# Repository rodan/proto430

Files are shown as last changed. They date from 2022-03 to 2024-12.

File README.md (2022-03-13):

## proto430

 ////// UNDER DEVELOPMENT ///////////////////////

 BoosterPack-compatible development boards used for quick prototyping and interfacing with i2c/spi/uart-based devices

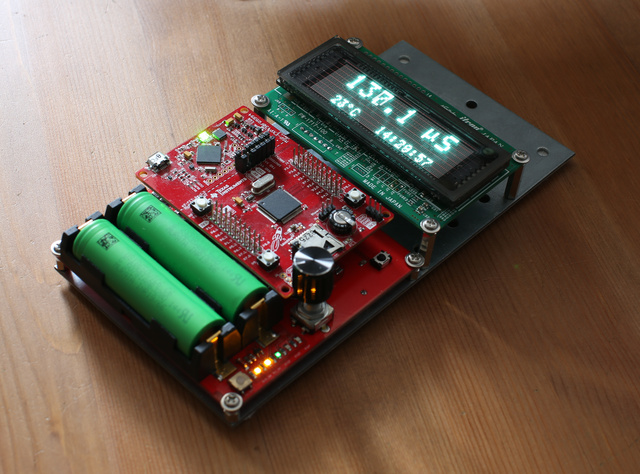
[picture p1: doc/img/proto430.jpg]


```
 source:       https://github.com/rodan/proto430
 author:       Petre Rodan <2b4eda@subdimension.ro>
 license:      BSD
```

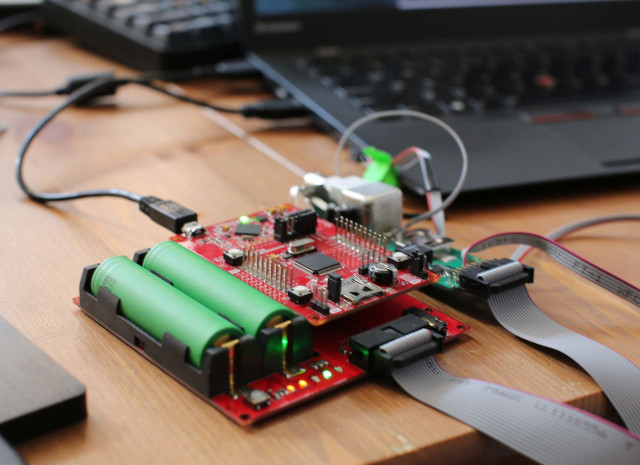
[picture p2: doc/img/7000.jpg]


### Components

Collection of plug-in Booster-Pack PCBs compatible with the Texas Instruments LaunchPad development ecosystem. one board provides access to any 3v3 device via a serial interface, the other brings access to a graphical VFD display, a rotary encoder and also has infrared remote input. the two will be linked via i2c or spi.

project directory structure

 * ./hardware/display.* - eagle-based schematics and pcbs for the spi-based Noritake VFD 
 * ./hardware/sensor.*  - eagle-based schematics and pcbs for the i2c/spi/uart devboard
 * ./hardware/vfd.* - firmware for the display pcb

testing is done with MSP-EXP430FR5994 development kits

### Build requirements

you will need TI's excelent [GCC toolchain](https://www.ti.com/tool/MSP430-GCC-OPENSOURCE) or Code Composer Studio for linux and my [reference libraries for msp430 micros](https://github.com/rodan/atlas430) cloned in /opt/.

```
cd ./firmware
make
make install
```

the devboard has been modified by adding a 16MHz high frequency crystal and two load capacitors. if these components are missing from your board then make sure to disable the *USE_XT2* define from the Makefile or CCS.

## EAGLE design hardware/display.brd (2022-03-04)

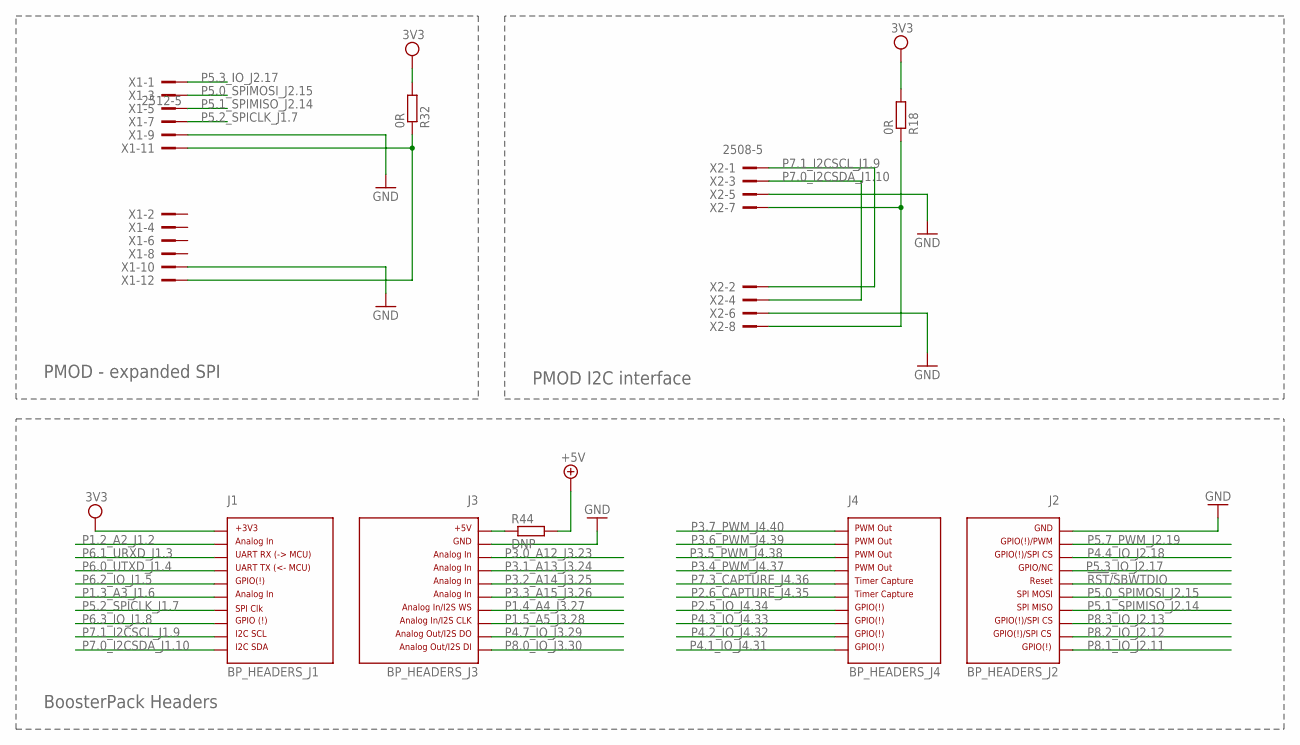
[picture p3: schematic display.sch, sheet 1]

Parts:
J1: BP_HEADERS_J1; J1
J2: BP_HEADERS_J2; J2
J3: BP_HEADERS_J3; J3
J4: BP_HEADERS_J4; J4
R18, R32: 0R; 0204V
R44: DNP; R0805W
X1: 2512-5; PAK100/2500-5-12
X2: 2508-5; PAK100/2500-5-08

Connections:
3V3: J1.1, R18.2, R32.2; also elsewhere on the board
!RST!/SBWTDIO: J2.16
+5V: R44.2; also elsewhere on the board
GND: J2.20, J3.22, X1.9, X1.10, X2.5, X2.6; also elsewhere on the board
unnamed: R18.1, X2.7, X2.8
unnamed: R32.1, X1.11, X1.12
unnamed: J3.21, R44.1
P1.2_A2_J1.2: J1.2; also elsewhere on the board
P1.3_A3_J1.6: J1.6; also elsewhere on the board
P1.4_A4_J3.27: J3.27; also elsewhere on the board
P1.5_A5_J3.28: J3.28; also elsewhere on the board
P2.5_IO_J4.34: J4.34; also elsewhere on the board
P2.6_CAPTURE_J4.35: J4.35; also elsewhere on the board
P3.0_A12_J3.23: J3.23; also elsewhere on the board
P3.1_A13_J3.24: J3.24; also elsewhere on the board
P3.2_A14_J3.25: J3.25; also elsewhere on the board
P3.3_A15_J3.26: J3.26; also elsewhere on the board
P3.4_PWM_J4.37: J4.37
P3.5_PWM_J4.38: J4.38
P3.6_PWM_J4.39: J4.39
P3.7_PWM_J4.40: J4.40
P4.1_IO_J4.31: J4.31
P4.2_IO_J4.32: J4.32
P4.3_IO_J4.33: J4.33
P4.4_IO_J2.18: J2.18; also elsewhere on the board
P4.7_IO_J3.29: J3.29
P5.0_SPIMOSI_J2.15: J2.15, X1.3; also elsewhere on the board
P5.1_SPIMISO_J2.14: J2.14, X1.5; also elsewhere on the board
P5.2_SPICLK_J1.7: J1.7, X1.7; also elsewhere on the board
P5.3_IO_J2.17: J2.17, X1.1
P5.7_PWM_J2.19: J2.19; also elsewhere on the board
P6.0_UTXD_J1.4: J1.4
P6.1_URXD_J1.3: J1.3
P6.2_IO_J1.5: J1.5
P6.3_IO_J1.8: J1.8; also elsewhere on the board
P7.0_I2CSDA_J1.10: J1.10, X2.3, X2.4; also elsewhere on the board
P7.1_I2CSCL_J1.9: J1.9, X2.1, X2.2; also elsewhere on the board
P7.3_CAPTURE_J4.36: J4.36; also elsewhere on the board
P8.0_IO_J3.30: J3.30
P8.1_IO_J2.11: J2.11; also elsewhere on the board
P8.2_IO_J2.12: J2.12; also elsewhere on the board
P8.3_IO_J2.13: J2.13; also elsewhere on the board

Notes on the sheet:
BoosterPack Headers
PMOD - expanded SPI
PMOD I2C interface

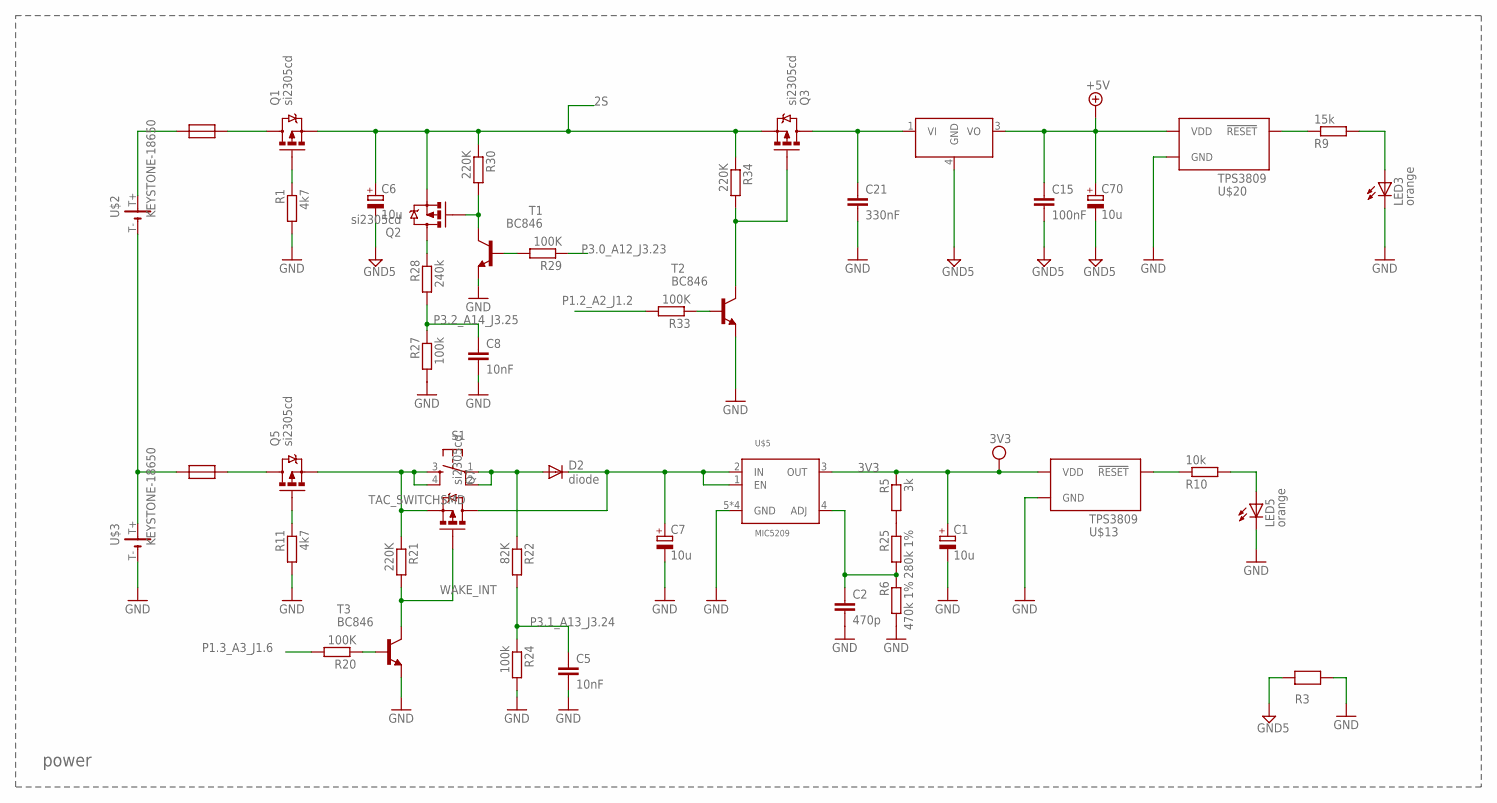
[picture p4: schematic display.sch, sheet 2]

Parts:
C1, C6, C7, C70: 10u; 153CLV-0405
C2: 470p; C0805
C5, C8: 10nF; C0805
C15: 100nF; C0805
C21: 330nF; C0805
D2: diode; SMA-DIODE
LED3, LED5: orange; CHIPLED_0805
Q1, Q2, Q3, Q5, Q7: si2305cd; SOT23-3_POWER
R1, R11: 4k7; R0805W
R3: 0R_0805; R0805W
R5: 3k; R0805W
R6: 470k 1%; R0805W
R9: 15k; R0805W
R10: 10k; R0805W
R20, R29, R33: 100K; R0805W
R21, R30, R34: 220K; R0805W
R22: 82K; R0805W
R24, R27: 100k; R0805W
R25: 280k 1%; R0805W
R28: 240k; R0805W
S1: TAC_SWITCHSMD; TACTILE-SWITCH-SMD
T1, T2, T3: BC846; SOT23
U4: 7805; D2PACK
U$2, U$3: KEYSTONE-18650; KEYSTONE_COMBO_18650
U$5: MIC5209; SO-08
U$7, U$8: Fuse 1A; 0805W
U$13, U$20: TPS3809; R_PDSO_G3

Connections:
2S: C6.+, Q1.2 (S), Q2.2 (S), Q3.2 (S), R30.1, R34.1; also elsewhere on the board
3V3: C1.+, R5.1, U$5.3 (OUT), U$13.P$3 (VDD); also elsewhere on the board
+5V: C15.1, C70.+, U4.3 (VO), U$20.P$3 (VDD); also elsewhere on the board
GND: C1.-, C2.2, C5.2, C7.-, C8.2, C21.2, LED3.C, LED5.C, R1.2, R3.2, R6.2, R11.2, R24.2, R27.2, T1.2 (E), T2.2 (E), T3.2 (E), U$3.T- (-), U$5.5 (GND), U$5.6 (GND), U$5.7 (GND), U$5.8 (GND), U$13.P$1 (GND), U$20.P$1 (GND); also elsewhere on the board
GND5: C6.-, C15.2, C70.-, R3.1, U4.4 (GND); also elsewhere on the board
unnamed: C21.1, Q3.3 (D), U4.1 (VI)
unnamed: Q1.1 (G), R1.1
unnamed: Q5.2 (S), Q7.2 (S), R21.1, S1.3, S1.4
unnamed: LED3.A, R9.2
unnamed: C2.1, R6.1, R25.2, U$5.4 (ADJ)
unnamed: Q1.3 (D), U$7.2
unnamed: Q5.3 (D), U$8.2
unnamed: R9.1, U$20.P$2 (!RESET)
unnamed: LED5.A, R10.2
unnamed: R10.1, U$13.P$2 (!RESET)
unnamed: C7.+, D2.C, Q7.3 (D), U$5.1 (EN), U$5.2 (IN)
unnamed: Q5.1 (G), R11.1
unnamed: R5.2, R25.1
unnamed: Q2.3 (D), R28.1
unnamed: Q2.1 (G), R30.2, T1.3 (C)
unnamed: R20.1, T3.1 (B)
unnamed: R29.2, T1.1 (B)
unnamed: R33.1, T2.1 (B)
unnamed: Q3.1 (G), R34.2, T2.3 (C)
N_BAT1: U$2.T- (-), U$3.T+ (+), U$8.1
N_BAT2: U$2.T+ (+), U$7.1
P1.2_A2_J1.2: R33.2; also elsewhere on the board
P1.3_A3_J1.6: R20.2; also elsewhere on the board
P3.0_A12_J3.23: R29.1; also elsewhere on the board
P3.1_A13_J3.24: C5.1, R22.2, R24.1; also elsewhere on the board
P3.2_A14_J3.25: C8.1, R27.1, R28.2; also elsewhere on the board
PUSH: D2.A, R22.1, S1.1, S1.2
WAKE_INT: Q7.1 (G), R21.2, T3.3 (C); also elsewhere on the board

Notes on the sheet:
power

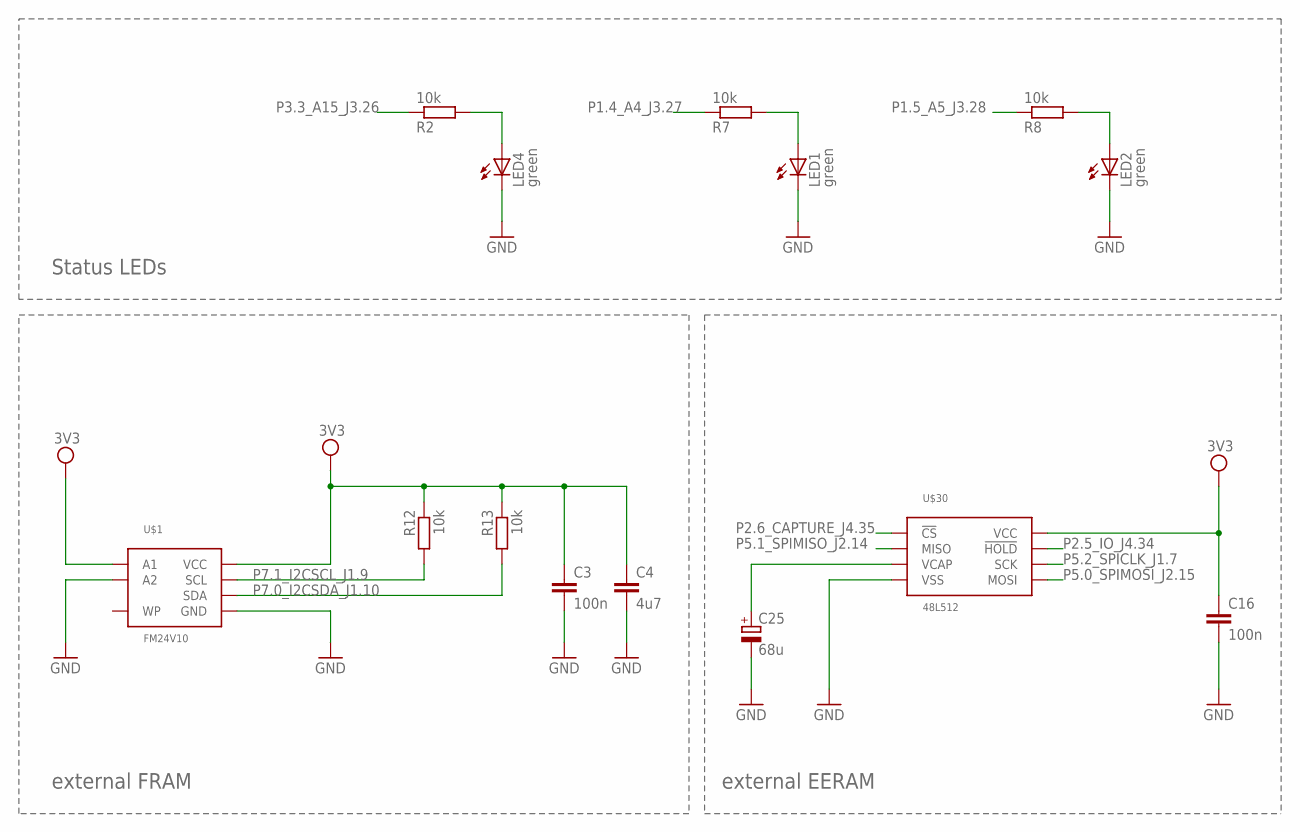
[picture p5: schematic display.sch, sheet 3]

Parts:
C3, C16: 100n; C0805
C4: 4u7; C0805
C25: 68u; SANYO-OSCON_SMD_C6
LED1, LED2, LED4: green; CHIPLED_0805
R2, R7, R8, R12, R13: 10k; R0805W
U$1: FM24V10; SO-08
U$30: 48L512; SO-08

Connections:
3V3: C3.1, C4.1, C16.1, R12.1, R13.1, U$1.2 (A1), U$1.8 (VCC), U$30.8 (VCC); also elsewhere on the board
GND: C3.2, C4.2, C16.2, C25.-, LED1.C, LED2.C, LED4.C, U$1.3 (A2), U$1.4 (GND), U$30.4 (VSS); also elsewhere on the board
unnamed: LED4.A, R2.2
unnamed: LED1.A, R7.2
unnamed: LED2.A, R8.2
unnamed: C25.+, U$30.3 (VCAP)
P1.4_A4_J3.27: R7.1; also elsewhere on the board
P1.5_A5_J3.28: R8.1; also elsewhere on the board
P2.5_IO_J4.34: U$30.7 (!HOLD); also elsewhere on the board
P2.6_CAPTURE_J4.35: U$30.1 (!CS); also elsewhere on the board
P3.3_A15_J3.26: R2.1; also elsewhere on the board
P5.0_SPIMOSI_J2.15: U$30.5 (MOSI); also elsewhere on the board
P5.1_SPIMISO_J2.14: U$30.2 (MISO); also elsewhere on the board
P5.2_SPICLK_J1.7: U$30.6 (SCK); also elsewhere on the board
P7.0_I2CSDA_J1.10: R13.2, U$1.5 (SDA); also elsewhere on the board
P7.1_I2CSCL_J1.9: R12.2, U$1.6 (SCL); also elsewhere on the board

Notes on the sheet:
external FRAM
Status LEDs
external EERAM

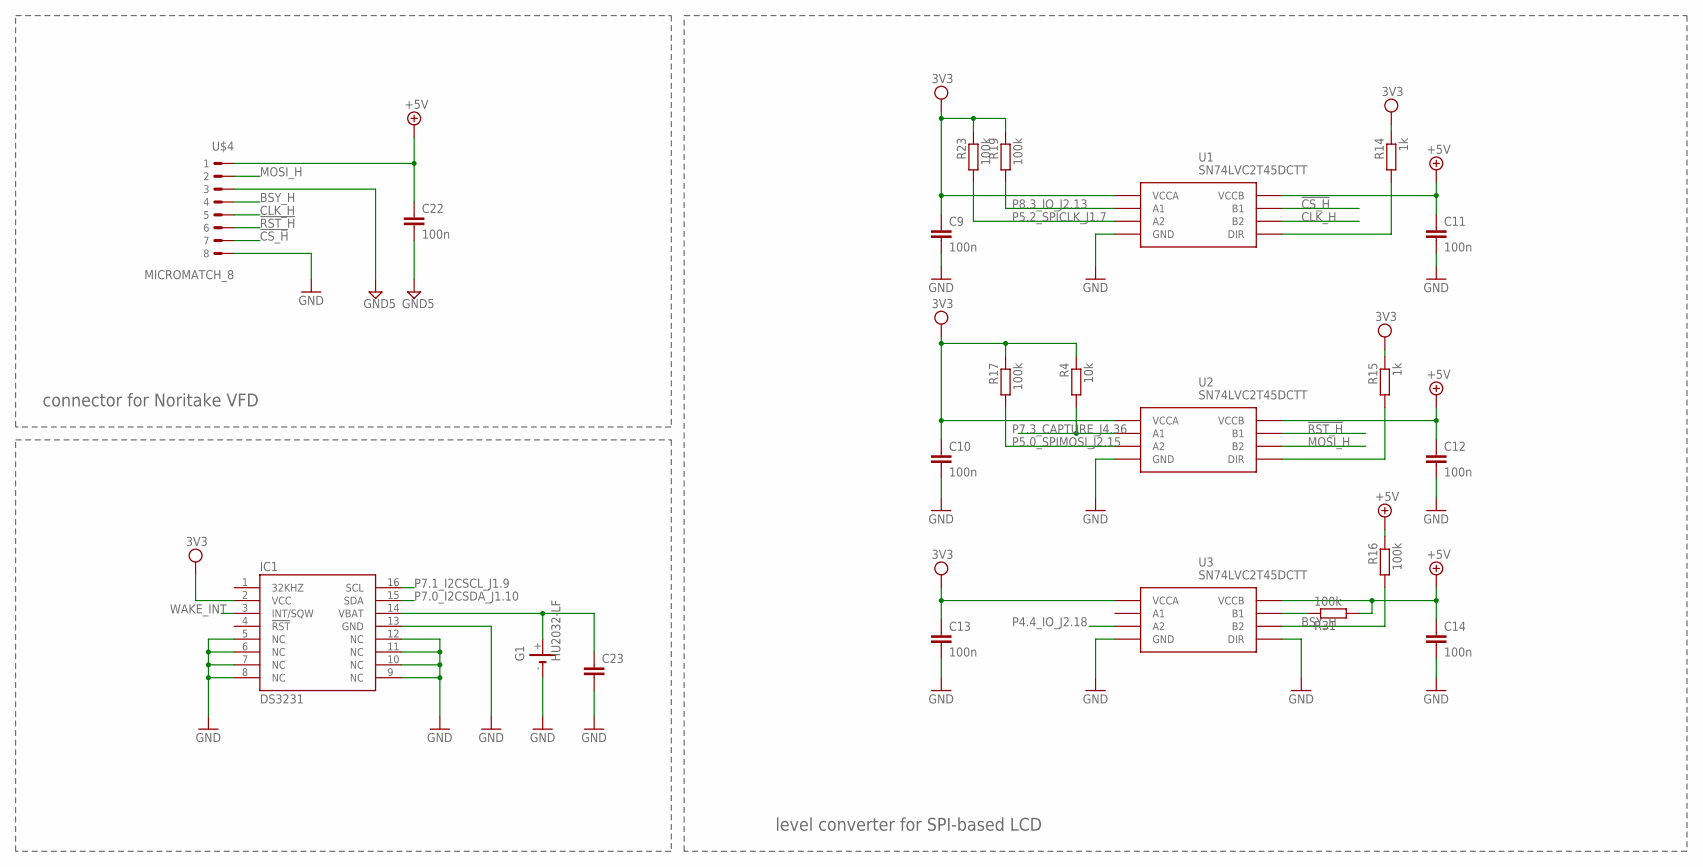
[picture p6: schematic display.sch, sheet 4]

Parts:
C9, C10, C11, C12, C13, C14, C22: 100n; C0805
C23: C-EU102-054X133; C102-054X133
G1: HU2032-LF
IC1: DS3231; SO-16
R4: 10k; R0805W
R14, R15: 1k; R0805W
R16, R17, R19, R23, R31: 100k; R0805W
U1, U2, U3: SN74LVC2T45DCTT; SSOP8
U$4: MICROMATCH_8; MICROMATCH8

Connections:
3V3: C9.1, C10.1, C13.1, IC1.2 (VCC), R4.1, R14.1, R15.1, R17.1, R19.1, R23.1, U1.P$1 (VCCA), U2.P$1 (VCCA), U3.P$1 (VCCA); also elsewhere on the board
!CS_H: U1.P$7 (B1), U$4.P$7 (7)
!RST_H: U2.P$7 (B1), U$4.P$6 (6)
+5V: C11.1, C12.1, C14.1, C22.1, R16.1, R31.2, U1.P$8 (VCCB), U2.P$8 (VCCB), U3.P$8 (VCCB), U$4.P$1 (1); also elsewhere on the board
BSY_H: R16.2, U3.P$6 (B2), U$4.P$4 (4)
CLK_H: U1.P$6 (B2), U$4.P$5 (5)
GND: C9.2, C10.2, C11.2, C12.2, C13.2, C14.2, C23.2, G1.-, IC1.5 (NC), IC1.6 (NC), IC1.7 (NC), IC1.8 (NC), IC1.9 (NC), IC1.10 (NC), IC1.11 (NC), IC1.12 (NC), IC1.13 (GND), U1.P$4 (GND), U2.P$4 (GND), U3.P$4 (GND), U3.P$5 (DIR), U$4.P$8 (8); also elsewhere on the board
GND5: C22.2, U$4.P$3 (3); also elsewhere on the board
MOSI_H: U2.P$6 (B2), U$4.P$2 (2)
unnamed: R14.2, U1.P$5 (DIR)
unnamed: R15.2, U2.P$5 (DIR)
unnamed: R31.1, U3.P$7 (B1)
unnamed: C23.1, G1.+, IC1.14 (VBAT)
P4.4_IO_J2.18: U3.P$3 (A2); also elsewhere on the board
P5.0_SPIMOSI_J2.15: R17.2, U2.P$3 (A2); also elsewhere on the board
P5.2_SPICLK_J1.7: R23.2, U1.P$3 (A2); also elsewhere on the board
P7.0_I2CSDA_J1.10: IC1.15 (SDA); also elsewhere on the board
P7.1_I2CSCL_J1.9: IC1.16 (SCL); also elsewhere on the board
P7.3_CAPTURE_J4.36: R4.2, U2.P$2 (A1); also elsewhere on the board
P8.3_IO_J2.13: R19.2, U1.P$2 (A1); also elsewhere on the board
WAKE_INT: IC1.3 (INT/SQW); also elsewhere on the board

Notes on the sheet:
connector for Noritake VFD
level converter for SPI-based LCD

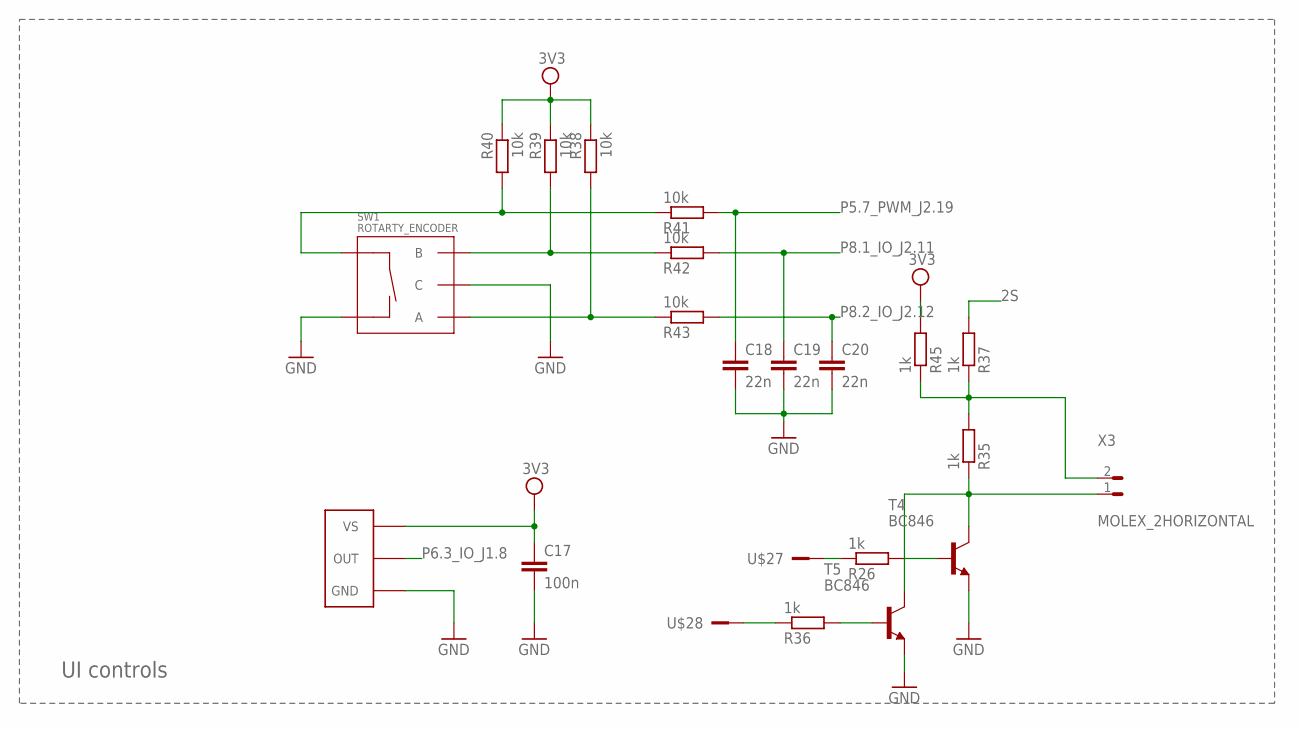
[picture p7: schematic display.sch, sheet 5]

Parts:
C17: 100n; C0805
C18, C19, C20: 22n; C0805
R26, R35, R36, R37, R45: 1k; R0805W
R38, R39, R40, R41, R42, R43: 10k; R0805W
SW1: ROTARTY_ENCODER; ROTARY_ENC_PLAIN
T4, T5: BC846; SOT23
U$26: TSOP36X; TSOP36X_SMD
U$27, U$28: TP; TP_THT
X3: MOLEX_2HORIZONTAL; 0530480210

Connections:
2S: R37.2; also elsewhere on the board
3V3: C17.1, R38.1, R39.1, R40.1, R45.2, U$26.P$3 (VS); also elsewhere on the board
GND: C17.2, C18.2, C19.2, C20.2, SW1.C, SW1.SW-, T4.2 (E), T5.2 (E), U$26.P$1 (GND); also elsewhere on the board
unnamed: R35.2, R37.1, R45.1, X3.2 (1)
unnamed: R26.2, T4.1 (B)
unnamed: R35.1, T4.3 (C), T5.3 (C), X3.1 (2)
unnamed: R26.1, U$27.1
unnamed: R40.2, R41.1, SW1.SW+
unnamed: R39.2, R42.1, SW1.B
unnamed: R38.2, R43.1, SW1.A
unnamed: R36.2, T5.1 (B)
unnamed: R36.1, U$28.1
P5.7_PWM_J2.19: C18.1, R41.2; also elsewhere on the board
P6.3_IO_J1.8: U$26.P$4 (OUT); also elsewhere on the board
P8.1_IO_J2.11: C19.1, R42.2; also elsewhere on the board
P8.2_IO_J2.12: C20.1, R43.2; also elsewhere on the board

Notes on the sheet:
UI controls

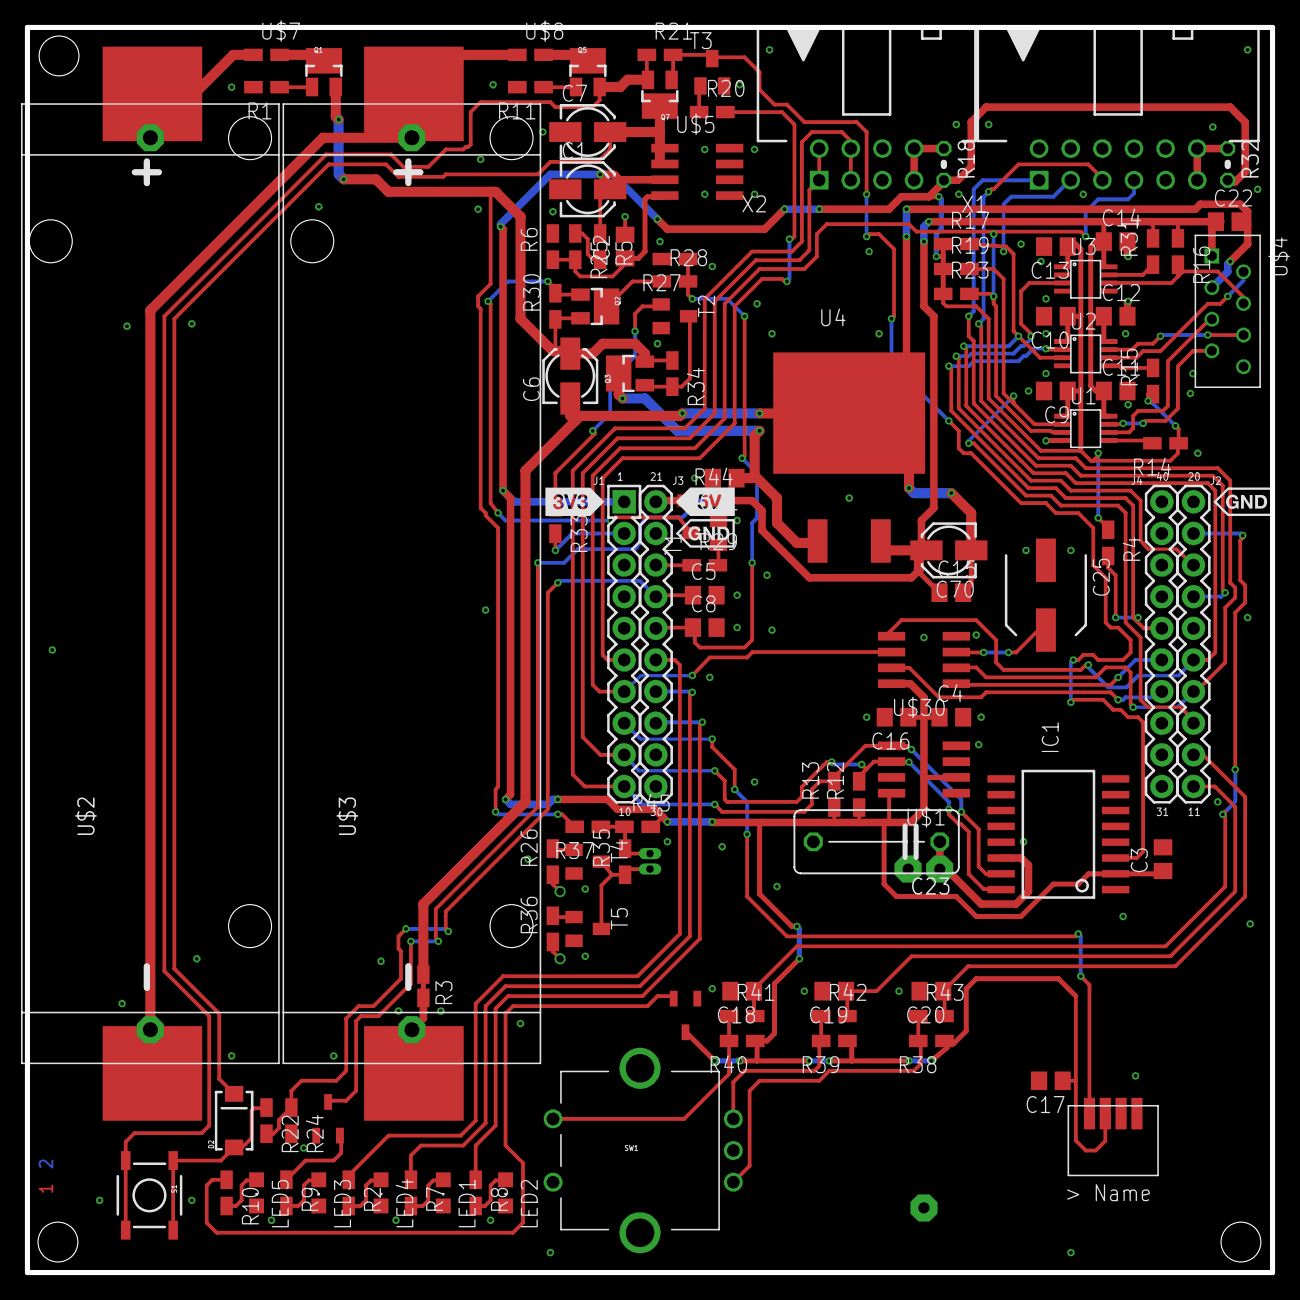
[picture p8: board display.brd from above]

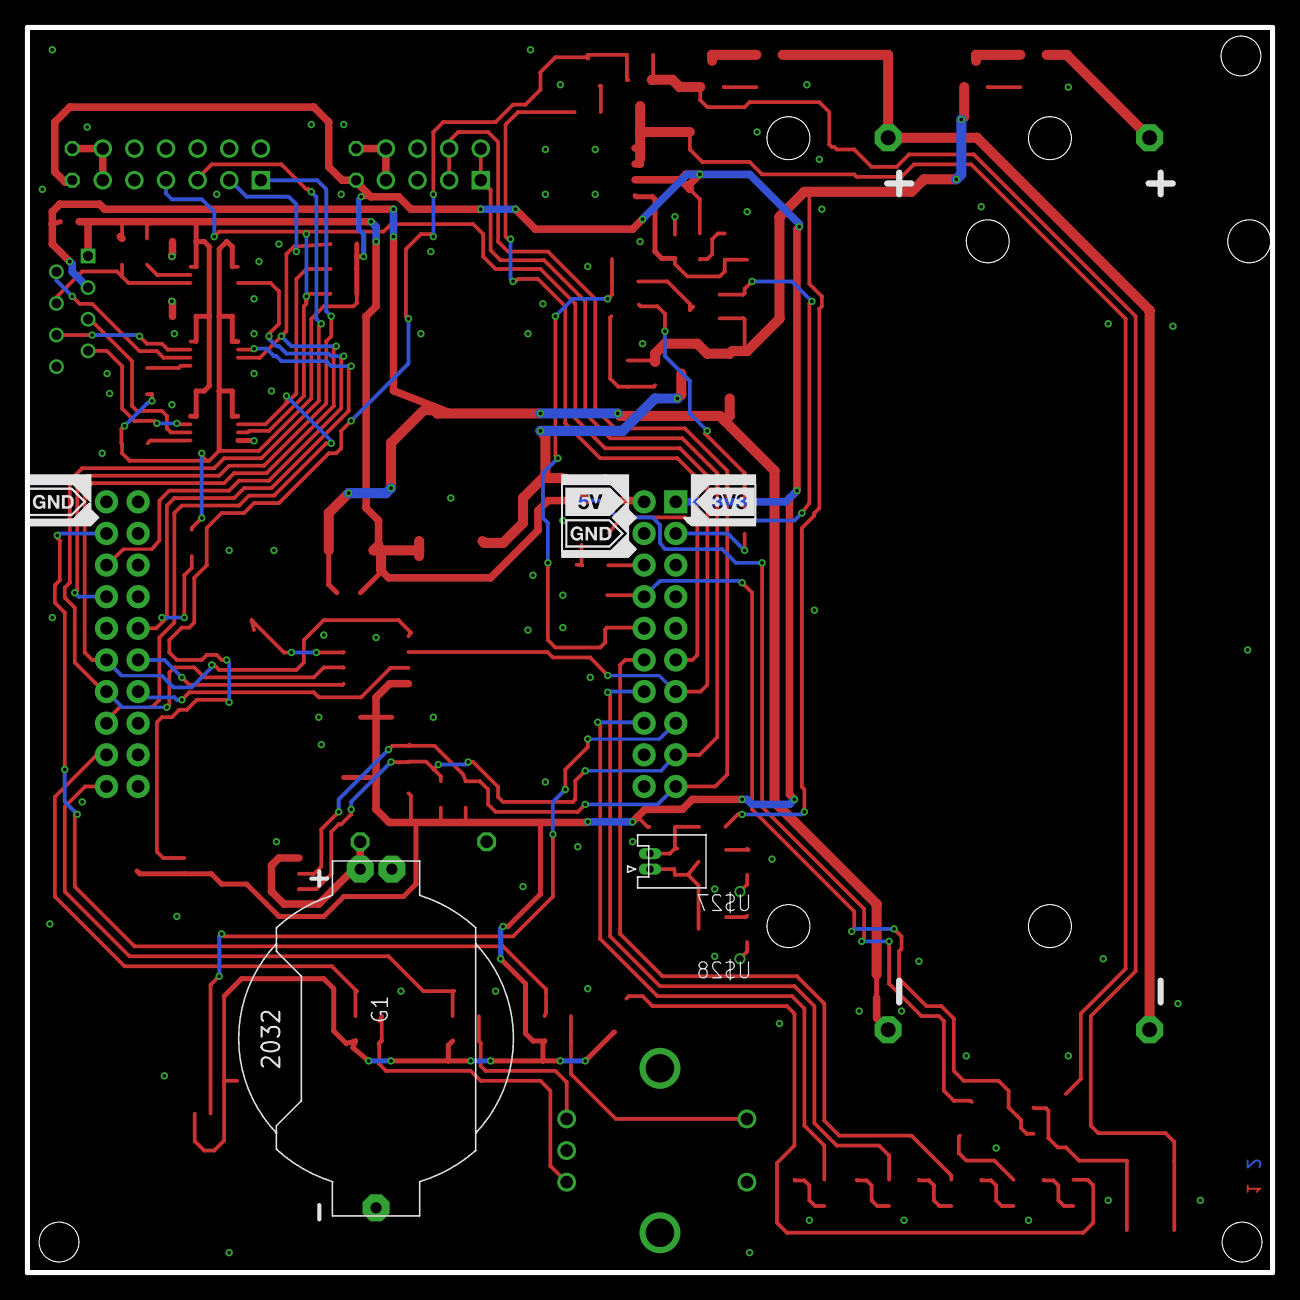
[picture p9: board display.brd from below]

Board: 2 copper layers, 100.0 x 100.0 mm, 114 parts (2 on the bottom side), 76 nets.

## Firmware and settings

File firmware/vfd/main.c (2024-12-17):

/*
    reference MSP430 library for an HI6000 EDGE probe

    tweak the baud rate in config.h
*/

#include <msp430.h>
#include <stdio.h>
#include <string.h>
#include <inttypes.h>

#include "proj.h"
#include "driverlib.h"
#include "glue.h"
#include "ui.h"
#include "timer_a1.h"
#include "timer_a2.h"
#include "timer_a3.h"
#include "adc.h"
#include "list_helper.h"
#include "version.h"
#include "jig.h"
#include "sig.h"
#include "rotary_encoder.h"
#include "eeram_48l_extra.h"
#include "vfd_extra.h"
#include "ir_remote_extra.h"

volatile uint8_t port3_last_event;
volatile uint8_t port5_last_event;
uint32_t button_down_start;

uint32_t vbat_cell_1;
uint32_t vbat_cell_2;
uint32_t vbat_cell_t;

uart_descriptor bc; // backchannel uart interface
extern struct ts t;

#define ADC_REFRESH_INTERVAL 3600UL // time in seconds between consecutive measurements of the battery voltage

void main_init(void)
{
    P3DIR = 0x3d;

    // activate pullup
    P3OUT = 0xc0;
    P3REN = 0xc0;

    // IRQ triggers on rising edge
    P3IES &= ~BIT1;

    // P44 is display BSY
    P4DIR = 0xef;

    // P55 and P56 are buttons
    // P57 is rot enc sw
    P5DIR = 0x1f;

    // activate pullup
    P5OUT = 0x60;
    P5REN = 0x60;

    // IRQ triggers on the falling edge
    P5IES = 0xe0;

    // P63 is the IR sensor
    P6DIR = 0xf7;

    // P81 and P82 are rot encoder signals
    P8DIR = 0xf9;

    rail_3v3_on;
}

void i2c_init(void)
{
    i2c_pin_init();

#if I2C_USE_DEV > 3
    // enhanced USCI capable microcontroller
    EUSCI_B_I2C_initMasterParam param = {0};

    param.selectClockSource = EUSCI_B_I2C_CLOCKSOURCE_SMCLK;
    param.i2cClk = SMCLK_FREQ;
    param.dataRate = EUSCI_B_I2C_SET_DATA_RATE_400KBPS;
    param.byteCounterThreshold = 0;
    param.autoSTOPGeneration = EUSCI_B_I2C_NO_AUTO_STOP;
    EUSCI_B_I2C_initMaster(I2C_BASE_ADDR, &param);
#elif I2C_USE_DEV < 4
    // USCI capable microcontroller
    USCI_B_I2C_initMasterParam param = {0};

    param.selectClockSource = USCI_B_I2C_CLOCKSOURCE_SMCLK;
    param.i2cClk = SMCLK_FREQ;
    param.dataRate = USCI_B_I2C_SET_DATA_RATE_400KBPS;
    USCI_B_I2C_initMaster(I2C_BASE_ADDR, &param);
#endif

    i2c_irq_init(I2C_BASE_ADDR);
}

void spi_init(void)
{

    spi_pin_init();

#if defined __MSP430_HAS_EUSCI_Bx__
    EUSCI_B_SPI_initMasterParam param = {0};
    param.selectClockSource = EUSCI_B_SPI_CLOCKSOURCE_SMCLK;
    param.clockSourceFrequency = SMCLK_FREQ;
    param.desiredSpiClock = 1000000;
    param.msbFirst= EUSCI_B_SPI_MSB_FIRST;
    param.clockPhase= EUSCI_B_SPI_PHASE_DATA_CHANGED_ONFIRST_CAPTURED_ON_NEXT;
    param.clockPolarity = EUSCI_B_SPI_CLOCKPOLARITY_INACTIVITY_HIGH;
    param.spiMode = EUSCI_B_SPI_3PIN;
    EUSCI_B_SPI_initMaster(SPI_BASE_ADDR, &param);
    EUSCI_B_SPI_enable(SPI_BASE_ADDR);

#elif defined __MSP430_HAS_USCI_Bx__
    USCI_B_SPI_initMasterParam param = {0};
    param.selectClockSource = USCI_B_SPI_CLOCKSOURCE_SMCLK;
    param.clockSourceFrequency = SMCLK_FREQ;
    param.desiredSpiClock = 1000000;
    param.msbFirst= USCI_B_SPI_MSB_FIRST;
    param.clockPhase= USCI_B_SPI_PHASE_DATA_CHANGED_ONFIRST_CAPTURED_ON_NEXT;
    param.clockPolarity = USCI_B_SPI_CLOCKPOLARITY_INACTIVITY_HIGH;
    USCI_B_SPI_initMaster(SPI_BASE_ADDR, &param);
    USCI_B_SPI_enable(SPI_BASE_ADDR);
#endif
}

void spi_pause(void)
{
    // zero out BSY signal
    //P3IE &= ~BIT7;
    //P3OUT &= ~BIT7;

    // zero out SPI pins
    //P5SEL0 &= ~(BIT0 | BIT1 | BIT2);
    //P5SEL1 &= ~(BIT0 | BIT1 | BIT2);
    //P5DIR &= ~(BIT0 | BIT1 | BIT2 | BIT3);
    //P5OUT &= ~(BIT0 | BIT1 | BIT2);
    //P5REN |= BIT0 | BIT1 | BIT2;
}

void spi_resume(void)
{
    // restore BSY signal
    //P3IFG &= ~BIT7;
    //P3OUT |= BIT7;
    //P3IE |= BIT7;

    // restore SPI pins
    //P5REN &= (BIT0 | BIT1 | BIT2);
    //spi_pin_init();
    //P5DIR |= BIT3;
}

static void button_31_irq(uint32_t msg)
{
    if (P3IN & BIT1) {
        timer_a2_set_trigger_slot(SCHEDULE_PB_31_OFF, systime() + 300, TIMER_A2_EVENT_ENABLE);
        timer_a2_set_trigger_slot(SCHEDULE_POWER_SAVING, systime() + POWER_SAVING_DELAY,
                                  TIMER_A2_EVENT_ENABLE);
#ifdef P31_ADC
        // Reset IRQ flags
        P3IFG &= ~BIT1;
        // disable button interrupt
        P3IE &= ~BIT1;

        // start vref
        vref_init();
        // set pin as analog input
        //adc_init(ADC_1_CELL);
        P3SEL1 |= BIT1;
        P3SEL0 |= BIT1;
        // trigger a conversion in a few ms
        timer_a2_set_trigger_slot(SCHEDULE_ADC_1CELL, systime() + 3, TIMER_A2_EVENT_ENABLE);
#else
        // IRQ triggers on falling edge
        P3IES |= BIT1;
#endif
    } else {
        timer_a2_set_trigger_slot(SCHEDULE_PB_31_OFF, 0, TIMER_A2_EVENT_DISABLE);
        // IRQ triggers on rising edge
        P3IES &= ~BIT1;
    }
}

#if 0
static void jig_ready_handler(uint32_t msg)
{
    jig_7000_read(0x0, jig_data, 23);
    
    if (P1OUT & BIT2) {
        ui_vfd_refresh();
    }
}
#endif

static void button_55_irq(uint32_t msg)
{
    if (P5IN & BIT5) {
        timer_a2_set_trigger_slot(SCHEDULE_PB_55, 0, TIMER_A2_EVENT_DISABLE);
    } else {
        timer_a2_set_trigger_slot(SCHEDULE_PB_55, systime() + 100, TIMER_A2_EVENT_ENABLE);
    }
}

static void button_55_long_press_irq(uint32_t msg)
{
    uart_print(&bc, "PB55 long\r\n");
}

static void button_56_irq(uint32_t msg)
{
    if (P5IN & BIT6) {
        sig0_off;
        timer_a2_set_trigger_slot(SCHEDULE_PB_56, 0, TIMER_A2_EVENT_DISABLE);
    } else {
        timer_a2_set_trigger_slot(SCHEDULE_PB_56, systime() + 100, TIMER_A2_EVENT_ENABLE);
    }
}

static void button_56_long_press_irq(uint32_t msg)
{
    uart_print(&bc, "PB56 long\r\n");
}

static void button_57_irq(uint32_t msg)
{
    if (P5IN & BIT7) {
        sig0_off;
        timer_a2_set_trigger_slot(SCHEDULE_PB_57, 0, TIMER_A2_EVENT_DISABLE);
    } else {
        timer_a2_set_trigger_slot(SCHEDULE_PB_57, systime() + 100, TIMER_A2_EVENT_ENABLE);
    }
}

static void button_57_long_press_irq(uint32_t msg)
{
    uart_print(&bc, "PB57 long\r\n");

    rail_5v_on;
    //timer_a2_set_trigger_slot(SCHEDULE_VFD_REFRESH, systime()+100, TIMER_A2_EVENT_ENABLE);
    //timer_a2_set_trigger_slot(SCHEDULE_RTC_REFRESH, systime()+20, TIMER_A2_EVENT_ENABLE);
}

/*
static void led_on_irq(uint32_t msg)
{
    sig4_on;
    timer_a2_set_trigger_slot(SCHEDULE_LED_OFF, systime() + 100, TIMER_A2_EVENT_ENABLE);
}

static void led_off_irq(uint32_t msg)
{
    sig4_off;
    timer_a2_set_trigger_slot(SCHEDULE_LED_ON, systime() + 100, TIMER_A2_EVENT_ENABLE);
}
*/

static void poweroff_irq(uint32_t msg)
{
    halt();
}

static void scheduler_irq(uint32_t msg)
{
    timer_a2_scheduler_handler();
}

void halt(void)
{
    rail_5v_off;
    rail_3v3_off;
    sig0_on;
    sig1_off;
    sig2_off;
    sig3_off;
    sig4_off;
}

/*
static void vfd_refresh(uint32_t msg)
{
    ui_vfd_refresh();
    timer_a2_set_trigger_slot(SCHEDULE_VFD_REFRESH, systime()+100, TIMER_A2_EVENT_ENABLE);
}
*/

static void rtc_refresh(uint32_t msg)
{
    DS3231_get(I2C_BASE_ADDR, &t);
    timer_a2_set_trigger_slot(SCHEDULE_RTC_REFRESH, systime()+100, TIMER_A2_EVENT_ENABLE);
}

static void adc_rdy_irq(uint32_t msg)
{
    struct jig_t *jig;
    struct adc_t *adc;

    adc = adc_get_p();

    switch (adc->adc_ccp) {
#ifdef P31_ADC
    case ADC_1_CELL:
        // set pin as digital input with edge triggering
        P3SEL1 &= ~BIT1;
        P3SEL0 &= ~BIT1;
        P3DIR &= ~BIT1;
        if (P3IN & BIT1) {
            // user keeps pushing button
            // IRQ triggers on falling edge
            P3IES |= BIT1;
        } else {
            timer_a2_set_trigger_slot(SCHEDULE_PB_31_OFF, 0, TIMER_A2_EVENT_DISABLE);
            // IRQ triggers on rising edge
            P3IES &= ~BIT1;
        }

        vbat_cell_1 = (uint32_t) adc->adc_mem *(uint32_t) 100 / (uint32_t) 902;      // 4096/(2.5 * 4.178 / 2.30)

        // Reset IRQ flags
        P3IFG &= ~BIT1;
        // Enable button interrupt
        P3IE |= BIT1;
        break;
 #endif
    case ADC_2_CELL:
        vbat_cell_t = (uint32_t) adc->adc_mem *(uint32_t) 100 / (uint32_t) 478;      // 4096/(2.5*8.368/2.442)
        //adc_2cell_check_off;
        break;
    case ADC_ID:
        break;
    default:
        break;
    }

    if (vbat_cell_t && vbat_cell_1) {
        vbat_cell_2 = vbat_cell_t - vbat_cell_1;
    }

    jig = jig_get_p();
    jig->adc_v1 = vbat_cell_1;
#ifdef P31_ADC
    jig->adc_v2 = vbat_cell_2;
#else
    jig->adc_v2 = vbat_cell_t;
#endif

    vref_halt();
    adc_halt();
}

#ifdef P31_ADC
static void adc_1cell_conv_start(uint32_t msg)
{
    struct adc_t *adc;

    if (P3IN & BIT1) {
        vref_init();
        adc_halt();
        ADC12MCTL0 = ADC12VRSEL_1 | ADC12INCH_13;
        ADC12CTL0 |= ADC12ON;
        ADC12CTL0 |= ADC12ENC | ADC12SC;
        adc = adc_get_p();
        adc->adc_ccp = ADC_1_CELL;
        //timer_a2_set_trigger_slot(SCHEDULE_ADC_1CELL, systime() + (ADC_REFRESH_INTERVAL * 100), TIMER_A2_EVENT_ENABLE);
    }
}
#endif

static void adc_2cell_conv_start(uint32_t msg)
{
    struct adc_t *adc;

    adc = adc_get_p();
    vref_init();
    adc_halt();
    ADC12MCTL0 = ADC12VRSEL_1 | ADC12INCH_14;
    ADC12CTL0 |= ADC12ON;
    ADC12CTL0 |= ADC12ENC | ADC12SC;
    adc->adc_ccp = ADC_2_CELL;
    timer_a2_set_trigger_slot(SCHEDULE_ADC_2CELL, systime() + (ADC_REFRESH_INTERVAL * 100), TIMER_A2_EVENT_ENABLE);
}

static void uart_bcl_rx_irq(uint32_t msg)
{
    parse_user_input();
    uart_set_eol(&bc);
    timer_a2_set_trigger_slot(SCHEDULE_POWER_SAVING, systime() + POWER_SAVING_DELAY,
                              TIMER_A2_EVENT_ENABLE);
}

#ifdef CONFIG_IR_RECEIVER
static void ir_remote_irq(uint32_t msg)
{
    ir_remote_mng();
}
#endif

void check_events(void)
{
    uint32_t msg = SYS_MSG_NULL;
    uint16_t ev;

    sig2_on;
    sig3_on;

    // uart RX
    if (uart_get_event(&bc) & UART_EV_RX) {
        msg |= SYS_MSG_UART_BCL_RX;
        uart_rst_event(&bc);
    }
    #if 0
    // vfd
    if (VFD_get_event(NULL) & VFD_EV_RDY) {
        msg |= SYS_MSG_VFD_TX_RDY;
        VFD_rst_event(NULL);
    }
    #endif
    #if 0
    // timer_a0
    ev = timer_a0_get_event();
    if (ev) {
        if (ev & TIMER_A0_EVENT_CCR1) {
            msg |= SYS_MSG_TIMERA0_CCR1;
        } else if (ev & TIMER_A0_EVENT_CCR2) {
            msg |= SYS_MSG_TIMERA0_CCR2;
        }
        timer_a0_rst_event();
    }
    #endif
    // timer_a1
#ifdef CONFIG_IR_RECEIVER
    ev = timer_a1_get_event();
    if (ev) {
        if (ev & TIMER_A1_EVENT_CCR0) {
            msg |= SYS_MSG_TIMERA1_CCR0;
        }
        timer_a1_rst_event();
    }
#endif
    // timer_a2
    ev = timer_a2_get_event();
    if (ev) {
        if (ev & TIMER_A2_EVENT_CCR1) {
            msg |= SYS_MSG_TIMERA2_CCR1;
        }
        timer_a2_rst_event();
    }

    // timer_a2-based scheduler
    ev = timer_a2_get_event_schedule();
    if (ev) {
        if ((ev & (1 << SCHEDULE_POWER_SAVING)) || (ev & (1 << SCHEDULE_PB_31_OFF))) {
            msg |= SYS_MSG_SCH_POWEROFF;
        }
        if (ev & (1 << SCHEDULE_ADC_2CELL)) {
            msg |= SYS_MSG_SCH_CONV_2CELL;
        }
        if (ev & (1 << SCHEDULE_ADC_1CELL)) {
            msg |= SYS_MSG_SCH_CONV_1CELL;
        }
        if (ev & (1 << SCHEDULE_PB_55)) {
            msg |= SYS_MSG_P55_TMOUT_INT;
        }
        if (ev & (1 << SCHEDULE_PB_56)) {
            msg |= SYS_MSG_P56_TMOUT_INT;
        }
        if (ev & (1 << SCHEDULE_PB_57)) {
            msg |= SYS_MSG_P57_TMOUT_INT;
        }
        if (ev & (1 << SCHEDULE_VFD_REFRESH)) {
            msg |= SYS_MSG_VFD_REFRESH;
        }
        if (ev & (1 << SCHEDULE_RTC_REFRESH)) {
            msg |= SYS_MSG_RTC_REFRESH;
        }

        timer_a2_rst_event_schedule();
    }

    // adc conversion
    ev = adc_get_event();
    if (ev) {
        msg |= SYS_MSG_ADC_CONV_RDY;
        adc_rst_event();
    }
    // push button P3.1, P3.3 int
    if (port3_last_event) {
        if (port3_last_event & BIT1) {
            msg |= SYS_MSG_P31_INT;
            port3_last_event ^= BIT1;
        }
        if (port3_last_event & BIT7) {
            msg |= SYS_MSG_JIG_7000_RDY;
            port3_last_event ^= BIT7;
        }
        port3_last_event = 0;
    }
    // push button P5.x
    if (port5_last_event) {
        if (port5_last_event & BIT5) {
            msg |= SYS_MSG_P55_INT;
            port5_last_event ^= BIT5;
        }
        if (port5_last_event & BIT6) {
            msg |= SYS_MSG_P56_INT;
            port5_last_event ^= BIT6;
        }
        if (port5_last_event & BIT7) {
            msg |= SYS_MSG_P57_INT;
            port5_last_event ^= BIT7;
        }
    }

    sig3_off;
    eh_exec(msg);
    sig2_off;
}

int main(void)
{
    // stop watchdog
    WDTCTL = WDTPW | WDTHOLD;
    msp430_hal_init(HAL_GPIO_DIR_OUTPUT | HAL_GPIO_OUT_LOW);
#ifdef USE_SIG
    sig0_on;
#endif

    main_init();
    EERAM_48L_CS_high();
    VFD_CS_high();
    jig_7000_CS_high();

    clock_pin_init();
    clock_init();

    //timer_a0_init();            //
    timer_a2_init();    // scheduler, systime()
    timer_a3_init();    // rotary decoder

    bc.baseAddress = EUSCI_A0_BASE;
    bc.baudrate = BAUDRATE_57600;

    uart_pin_init(&bc);
    uart_init(&bc);
#if defined UART_RX_USES_RINGBUF
    uart_set_rx_irq_handler(&bc, uart_rx_ringbuf_handler);
#else
    uart_set_rx_irq_handler(&bc, uart_rx_simple_handler);
#endif

    adc_init(ADC_2_CELL);

    rot_enc_init();

#ifdef CONFIG_IR_RECEIVER
    ir_remote_init(IR_RST_SM);
#endif

    i2c_init();
    spi_init();

    EERAM_48L_init();
    VFD_init();
    jig_7000_init();
    spi_pause();

    sig0_off;
    sig1_off;
    sig2_off;
    sig3_off;

    eh_init();
    eh_register(&uart_bcl_rx_irq, SYS_MSG_UART_BCL_RX);
    eh_register(&button_31_irq, SYS_MSG_P31_INT);
    eh_register(&button_55_irq, SYS_MSG_P55_INT);
    eh_register(&button_56_irq, SYS_MSG_P56_INT);
    eh_register(&button_57_irq, SYS_MSG_P57_INT);

    eh_register(&poweroff_irq, SYS_MSG_SCH_POWEROFF);
    eh_register(&button_55_long_press_irq, SYS_MSG_P55_TMOUT_INT);
    eh_register(&button_56_long_press_irq, SYS_MSG_P56_TMOUT_INT);
    eh_register(&button_57_long_press_irq, SYS_MSG_P57_TMOUT_INT);

#ifdef CONFIG_IR_RECEIVER
    eh_register(&ir_remote_irq, SYS_MSG_TIMERA1_CCR0);
#endif
#ifdef P31_ADC
    eh_register(&adc_1cell_conv_start, SYS_MSG_SCH_CONV_1CELL);
#endif
    eh_register(&adc_2cell_conv_start, SYS_MSG_SCH_CONV_2CELL);
    eh_register(&adc_rdy_irq, SYS_MSG_ADC_CONV_RDY);

    eh_register(&scheduler_irq, SYS_MSG_TIMERA2_CCR1);
    //eh_register(&vfd_refresh, SYS_MSG_VFD_REFRESH);
    eh_register(&rtc_refresh, SYS_MSG_RTC_REFRESH);
    
    //eh_register(&jig_ready_handler, SYS_MSG_JIG_7000_RDY);

    timer_a2_set_trigger_slot(SCHEDULE_POWER_SAVING, POWER_SAVING_DELAY, TIMER_A2_EVENT_ENABLE);
//    timer_a2_set_trigger_slot(SCHEDULE_LED_ON, 200, TIMER_A2_EVENT_ENABLE);

    //display_menu();

    // Reset IRQ flags
    P3IFG = 0;
    // Enable button interrupt
    P3IE |= BIT1;

    // Reset IRQ flags
    P5IFG &= ~(BIT5 | BIT6 | BIT7);
    // Enable button interrupt
    P5IE |= BIT5 | BIT6 | BIT7;

    // fake button interrupt so we read the battery voltage
    button_31_irq(0);

    adc_2cell_check_on;
    vref_init();

#ifdef P31_ADC
    timer_a2_set_trigger_slot(SCHEDULE_ADC_1CELL, 5, TIMER_A2_EVENT_ENABLE);
#endif
    timer_a2_set_trigger_slot(SCHEDULE_ADC_2CELL, 50, TIMER_A2_EVENT_ENABLE);

    _BIS_SR(GIE);

    while (1) {
        // sleep
#ifdef LED_SYSTEM_STATES
        sig4_off;
#endif
        _BIS_SR(LPM3_bits + GIE);
#ifdef LED_SYSTEM_STATES
        sig4_on;
#endif
        __no_operation();
//#ifdef USE_WATCHDOG
//        WDTCTL = (WDTCTL & 0xff) | WDTPW | WDTCNTCL;
//#endif
        check_events();
        check_events();
        check_events();
    }
}

// Port 3 interrupt service routine
#if defined(__TI_COMPILER_VERSION__) || defined(__IAR_SYSTEMS_ICC__)
#pragma vector=PORT3_VECTOR
__interrupt void port3_isr_handler(void)
#elif defined(__GNUC__)
void __attribute__ ((interrupt(PORT3_VECTOR))) port3_isr_handler(void)
#else
#error Compiler not supported!
#endif
{
    switch (P3IV) {
    case P3IV__P3IFG1:
        port3_last_event |= BIT1;
        // listen for opposite edge
        P3IES ^= BIT1;
        //P3IFG &= ~TRIG1;
        _BIC_SR_IRQ(LPM3_bits);
        break;
    case P3IV__P3IFG7:
        port3_last_event |= BIT7;
        _BIC_SR_IRQ(LPM3_bits);
        break;
    }
    P3IFG = 0;
}

// Port 5 interrupt service routine
#if defined(__TI_COMPILER_VERSION__) || defined(__IAR_SYSTEMS_ICC__)
#pragma vector=PORT5_VECTOR
__interrupt void port5_isr_handler(void)
#elif defined(__GNUC__)
void __attribute__ ((interrupt(PORT5_VECTOR))) port5_isr_handler(void)
#else
#error Compiler not supported!
#endif
{
    switch (P5IV) {
    case P5IV__P5IFG5:
        port5_last_event |= BIT5;
        // listen for opposite edge
        P5IES ^= BIT5;
        _BIC_SR_IRQ(LPM3_bits);
        break;
    case P5IV__P5IFG6:
        port5_last_event |= BIT6;
        // listen for opposite edge
        P5IES ^= BIT6;
        _BIC_SR_IRQ(LPM3_bits);
        break;
    case P5IV__P5IFG7:
        port5_last_event |= BIT7;
        // listen for opposite edge
        P5IES ^= BIT7;
        _BIC_SR_IRQ(LPM3_bits);
        break;
    }
    P5IFG = 0;
}

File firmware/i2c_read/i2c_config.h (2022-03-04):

/**
* \addtogroup MOD_I2C
* \{
**/

/**
* \file
* \brief Configuration include file for \ref MOD_I2C
* \author Alex Mykyta 
**/

#ifndef __I2C_CONFIG_H__
#define __I2C_CONFIG_H__

//==================================================================================================
/// \name Configuration
/// Configuration defines for the \ref MOD_I2C module
/// \{
//==================================================================================================

//  ===================================================
//  = NOTE: Actual ports must be configured manually! =
//  ===================================================

/// Select which USCI module to use
#define I2C_USE_DEV      6    ///< \hideinitializer
/**<    0 = USCIB0 \n
*         1 = USCIB1 \n
*         2 = USCIB2 \n
*         3 = USCIB3 \n
*         4 = EUSCIB0 \n
*         5 = EUSCIB1 \n
*         6 = EUSCIB2 \n
*         7 = EUSCIB3 \n
**/

#define I2C_USES_UCB2

/// Select which clock source to use
#define I2C_CLK_SRC     2    ///< \hideinitializer
/**<    0 = External \n
*        1 = ACLK    \n
*        2 = SMCLK
**/

/// Clock Division (0x0004 to 0xFFFF)
#define I2C_CLK_DIV     20 ///< \hideinitializer

/// optional eUSCI Control Word Register 1
#define I2C_CWR1        0   ///< \hideinitializer

///\}

// eUSCI
#define I2C_BASE_ADDR       EUSCI_B2_BASE
#define I2C_ISR_VECTOR      EUSCI_B2_VECTOR


#endif
///\}

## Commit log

2022-03-04 initial import
    [display.brd, display.sch, sensor.brd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]
2022-03-09 i2c and spi transactions have to be separated a few ms from each other
2023-08-25 add i2c testing
2023-08-25 i2c-related updates
2023-10-17 pcb back from production, pin reconfiguration
2024-11-17 pin map update

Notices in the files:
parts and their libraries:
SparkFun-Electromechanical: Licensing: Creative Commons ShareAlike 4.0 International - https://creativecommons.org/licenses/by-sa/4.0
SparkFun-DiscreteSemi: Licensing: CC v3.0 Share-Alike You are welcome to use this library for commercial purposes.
